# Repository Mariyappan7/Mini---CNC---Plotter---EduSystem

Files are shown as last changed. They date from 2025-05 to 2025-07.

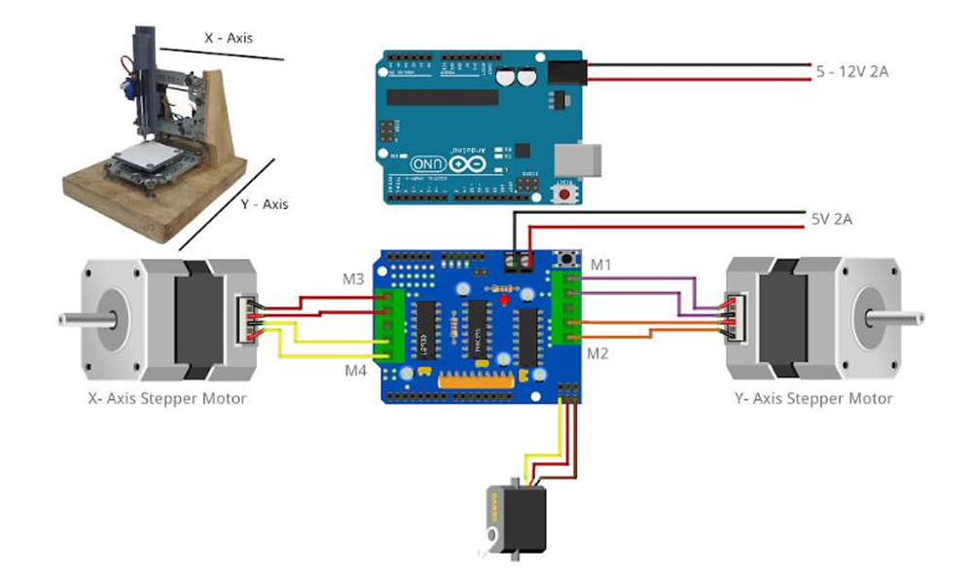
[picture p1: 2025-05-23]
Circuit Diagram.png

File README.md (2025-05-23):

# Mini---CNC---Plotter---EduSystem
This project is a compact and low-cost CNC plotter designed for educational purposes. Built using an Arduino-based control system, stepper motors, and a custom frame, it demonstrates the fundamentals of CNC motion control, G-code interpretation, and precision plotting. Ideal for learning automation, electronics, and mechanical design.

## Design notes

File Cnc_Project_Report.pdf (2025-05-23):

v

ABSTRACT

This project focuses on the comprehensive design and development of a low-

cost, compact, and educational CNC (Computer Numerical Control) drawing machine

tailored for academic and laboratory-based training environments. As CNC technology

becomes increasingly central to modern manufacturing and automation systems, it is

critical that students gain not only theoretical knowledge but also hands-on experience

with CNC equipment and digital fabrication workflows. However, in most educational

institutions, access to such systems remains limited due to their high cost, operational

complexity, and stringent safety requirements. To address this issue, the proposed

project introduces a simplified, 2-axis CNC plotter that utilizes open-source hardware

and software tools such as the Arduino Uno microcontroller, GRBL firmware for

motion control, and the Pronterface graphical interface. This machine is capable of

interpreting G-code commands and converting them into accurate, real-time movement

across X and Y axes to draw 2D shapes and vector-based designs on flat surfaces like

paper or acrylic sheets.

The project integrates fundamental elements from multiple branches of engineering,

making it a rich, multidisciplinary educational tool. Mechanically, the frame and motion

system are modeled using SolidWorks to ensure precision, stability, and ease of

fabrication. The structure is composed of lightweight materials such as aluminum

extrusions and 3D-printed parts to maintain strength while reducing cost. The motion is

enabled using DVD stepper motors to facilitate smooth and repeatable positioning.

Electrically, the system includes a servo motor to simulate Z-axis pen-lift motion,

offering a simplified yet effective method for tool engagement without the need for a

full spindle. On the programming side, GRBL firmware processes the G-code

instructions and generates corresponding electrical pulses, while Pronterface software

allows users to interface with the system, upload designs, and execute drawing

operations in real time.

vi

Overall, the Educational CNC Drawing Machine serves as an ideal training platform

for students pursuing education in mechanical, electrical, electronics, and computer

engineering disciplines. It reinforces key concepts such as motion planning, coordinate

systems, CAD/CAM integration, and firmware configuration, while also promoting

system-level thinking and problem-solving. The modular design enables easy

customization and future expansion, such as converting the plotter into a PCB milling

or laser engraving machine with minimal modifications. This project not only makes

CNC training more accessible and affordable but also bridges the gap between

classroom theory and industrial practice by bringing real-world automation

technologies directly into the learning environment. Its simplicity, functionality, and

educational value make it a powerful teaching tool for the next generation of engineers.

Keyword: CNC Drawing Machine, G-code Programming, Motion Control, Arduino

GRBL, Educational Automation, Open-source CNC, CAD/CAM Integration

vii

CHAPTER
NO
TITLE | PAGE NO
| ACKNOWLEDGEMENT | iv
| ABSTRACT | v
| TABLE OF CONTENTS | vii
| LIST OF FIGURES | x
| LIST OF TABLES | xi
1. | INTRODUCTION | 1
| 1.OBJECTIVE | 1
1.1 BACKGROUND OF THE WORK | 2
1.2 RELEVANCE OF CNC IN MODERN EDUCATION | 2
1.3 MOTIVATION AND SCOPE OF THE PROPOSED WORK | 3
1.4 COST AND USABILITY CONSIDERATIONS | 4
1.5 SOFTWARE AND FIRMWARE INTEGRATION | 5
1.6 MECHANICAL DESIGN OPTIMIZATION | 5
2. | LITERATURE SURVEY | 7

viii

2.1 LOW-COST MODULAR CNC PLOTTER FOR CLASSROOM LEARNING

7

2.2 SUSTAINABILITY-FOCUSED CNC PLOTTER USING RECYCLED COMPONENTS

8

2.3 CNC DRAWING SYSTEM FOR STEM EDUCATION AND CURRICULUM
INTEGRATION

8

2.4 MECHATRONICS-INTEGRATED CNC PLOTTER WITH CAD AND TOUCHSCREEN INTERFACE

9

2.5 MOTION AND CALIBRATION IN CNC SYSTEMS

9

2.6 SUMMARY OF GAPS AND PROBLEM IDENTIFICATION

10

3. | OBJECTIVES OF THE PROPOSED WORK | 11
| 3.1 OBJECTIVES OF THE PROPOSED WORK | 11
| 3.1.1 DESIGN AND DEVELOP THE MECHANICAL FRAMEWORK OF THE CNC PLOTTER | 12

3.1.2 IMPLEMENT MOTOR CONTROL AND ELECTRONICS INTEGRATION

12

3.1.3 DEVELOP AND CONFIGURE FIRMWARE AND G-CODE INTERPRETER

12

3.1.4 OPTIMIZE SYSTEM ACCURACY AND USER USABILITY

12

3.2 SYNTHETIC PROCEDURE/FLOW
DIAGRAM OF THE PROPOSED WORK

13

3.2.1 SYNTHETIC PROCEDURE | 13

ix

3.2.2 FLOW DIAGRAM | 15
3.3 SELECTION OF COMPONENTS, TOOLS, DATA COLLECTION, TECHNIQUES AND TESTING METHODS | 21
3.3.1 SELECTION OF COMPONENTS | 21
3.3.2 SOFTWARE TOOLS | 23
3.3.3 TOOLS AND EQUIPMENT | 23
3.3.4 DATA COLLECTION TECHNIQUES | 24
3.3.5 TECHNIQUES AND PROCEDURES | 24
3.3.6 TESTING METHODS | 25
3.3.7 STANDARDS AND BEST PRACTICES | 26

### 4. DESIGN AND PROPOSAL FOR CNC

PLOTTER

28

4.1 MECHANICAL SYSTEM DESIGN | 28
4.2 ELECTRONICS AND CIRCUIT DESIGN | 30
4.3 SOFTWARE CONTROL AND PROGRAMMING | 31
4.4 SUMMARY | 32
4.5 CALIBRATION AND TESTING PROCEDURE | 32

x

4.6 EDUCATIONAL SIGNIFICANCE AND USE-CASES

33

4.7 SOFTWARE FLOW FOR OPERATION
(FLOWCHART)

35

4.8 CHALLENGES FACED AND SOLUTIONS | 36
5. | RESULT AND DISCUSSION | 37
| 7.1 OVERVIEW OF TESTING AND CALIBRATION OUTCOMES | 37
| 7.2 PEN CONTROL AND SERVO RELIABILITY | 38
| 7.3 SOFTWARE AND G-CODE INTERPRETATION PERFORMANCE | 38
| 7.4 SURFACE COMPATIBILITY AND SHEET CONSTRAINTS | 39
| 7.5 REPEATABILITY AND PRECISION METRICS | 39
| 7.6 USER EXPERIENCE AND INTERFACE VALIDATION | 40
| 7.7 TESTING SUMMARY AND SYSTEM VALIDATION | 40
| 7.8 FUTURE DEVELOPMENTS | 41

### 6. CONCLUSIONS & SUGGESTIONS FOR

FUTURE WORK

43

REFERENCES | 47
APPENDIX | 49

xi

LIST OF FIGURES

FIGURE
NO
TITLE | PAGE NO
1.1 | STRUCTURE OF EDUCATIONAL CNC DRAWING MACHINE

3

1.2 SOFTWARE FLOW FOR DIAGRAM OPERATION

5

3.1 | ARDUINO UNO | 17
3.2 | STEPPER MOTOR | 18
3.3 | SERVO MOTOR FOR Z AXIS | 19
3.4 | L2983D DRIVER | 19
3.5 | WRITING AND DRAWING CNC MACHINE | 20
3.6 | BLOCK DIAGRAM | 25
4.1 | DESIGN OF CNC USING SOLIDWORKS | 29
4.2 | MASS PROPERTIES OF CNC | 30
4.3 | CIRCUIT DIAGRAM OF CNC | 31
4.4 | SOFTWARE FLOW CHART OF CNC | 35

xii

6.1 | FLOWCHART WITH END RESULT | 44

LIST OF TABLES

TABLE
NO
TITLE | PAGE NO
3.1 | SPECIFICATIONS OF ARDUINO UNO R3 | 14
4.1 | CHALLENGES FACED AND SOLUTIONS | 36
BILL OF MATERIAL | 49

CHAPTER – I

### INTRODUCTION

1.OBJECTIVE

In today’s technology-driven world, there is a growing demand for engineering

graduates with hands-on experience in practical tools such as CNC (Computer Numerical

Control) machines. CNC systems play a critical role in industries ranging from aerospace

to consumer goods manufacturing. However, many educational institutions still rely

heavily on theoretical instruction, limiting students’ understanding of real-world

applications. One of the major barriers to hands-on training is the cost and complexity of

commercial CNC machines, which are typically large, expensive, and require specialized

knowledge to operate. To address this gap, the Educational CNC Drawing Machine project

proposes the development of a compact, low-cost, and easy-to-use CNC plotter that enables

students to learn automation, motion control, G-code programming, and system integration

in a practical setting.

This machine is designed to draw precise 2D patterns on paper or lightweight surfaces

using a pen attached to a motorized gantry. By replicating the functions of large-scale CNC

machines in a scaled-down version, students gain exposure to real-time motion control,

axis calibration, firmware flashing, and interfacing with software such as Pronterface. The

machine uses open-source hardware like Arduino and GRBL firmware, making it highly

adaptable, customizable, and suitable for multidisciplinary engineering education. The

focus of this project is not only on building a functional machine but also on ensuring that

it becomes a powerful learning tool for students across mechanical, electrical, and

computer science domains.

### 1.1 Background of the Work

CNC machines are vital tools in modern manufacturing and production

environments. They automate the process of cutting, engraving, milling, or drawing based

on precise digital commands. However, the complexity and cost of full-scale CNC

machines make them impractical for use in academic labs, especially at the undergraduate

level. This has led to a demand for smaller, low-cost alternatives that replicate the core

functionalities of industrial CNC systems while being accessible and safe for students.

The Educational CNC Drawing Machine fits this niche by providing a platform for

understanding basic automation and control systems. It allows students to visualize the

relationship between software-generated code and physical machine movement. It also

introduces them to concepts like stepper motor control, pulse-width modulation, limit

switch triggering, and serial communication between microcontrollers and PCs.

### 1.2 Relevance of CNC In Modern Education

Integrating CNC concepts in education not only prepares students for manufacturing

jobs but also strengthens their understanding of robotics, IoT, embedded systems, and

mechatronics. With the Fourth Industrial Revolution emphasizing smart factories and

digital twins, the need for CNC literacy is higher than ever. Through this project, students

will be exposed to SolidWorks-based CAD design, CAM processes for G-code generation,

and motion execution via GRBL firmware. The machine’s ability to draw geometries like

circles, text, and curves also helps users appreciate the practical utility of coordinate

systems and numerical control.

This machine is built using components like aluminum extrusion profiles, DVD stepper

motors, a CNC shield, and Arduino Uno. The firmware is lightweight and compatible with

many open-source design tools. It’s safe, table-top design ensures it can be used even in

classrooms without dedicated labs or safety enclosures.

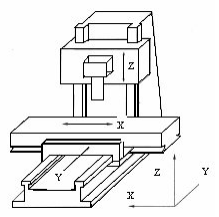
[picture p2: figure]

Figure 1.1 Structure of Educational CNC Drawing Machine

### 1.3 Motivation and Scope of The Proposed Work

The main motivation behind this project is to democratize access to CNC training

by creating an educational machine that is both affordable and practical. Traditional CNC

machines, although powerful, are often inaccessible to most institutions due to their cost,

maintenance needs, and operational complexity. Many students graduate without ever

using a CNC system, which limits their employability and confidence in automation

domains.

By designing a drawing CNC machine, the scope expands beyond mechanical tasks to

include training in software control, electronics integration, and embedded firmware. The

modularity of the system means that it can be customized for different use cases—

engraving, circuit plotting, or even laser cutting with minor upgrades. The machine also

provides a platform for learning system-level debugging, motion planning, and digital

fabrication.

Hands-on exposure to CNC operations helps students grasp complex engineering concepts

such as toolpath planning, machine kinematics, and feedback control. This project allows

them to generate G-code using simple tools and watch it being executed in real time. By working on this machine, students also learn teamwork, system design, prototyping, and

troubleshooting—all essential skills in engineering practice.

Another benefit is adaptability. This machine can be integrated into existing lab courses,

workshops, or competitions. It also supports multiple software workflows, from 2D vector

design to code simulation and execution. Students can extend the design by adding limit

switches, homing routines, or even Bluetooth-based control.

The Educational CNC Drawing Machine combines components and subsystems from

mechanical, electrical, and software domains. This multidisciplinary nature brings various

technical challenges that need to be addressed to ensure smooth functionality, safety, and

educational value. The primary areas of concern include system integration, power

management, mechanical accuracy, and firmware compatibility.

### 1.4 Cost and Usability Considerations

One of the biggest challenges was to design the machine within a constrained budget

without compromising on quality. Selecting affordable yet durable materials was key.

Aluminum profiles were used for the frame due to their light weight, strength, and

availability. 3D-printed parts were used for the pen holder and gantry mounts, reducing the

overall fabrication cost. Standard DVD stepper motors were chosen for axis control,

balancing torque and efficiency.

Usability was also a major concern. Since the machine is intended for students, the

interface had to be intuitive. Pronterface was selected for its visual layout and real-time

control features. The system provides basic control options like axis jogging, pen lifting,

and G-code uploading—enough to simulate actual industrial CNC workflows.

### 1.5 Software and Firmware Integration

A major technical challenge was synchronizing the firmware with software

commands to ensure accurate motion control. GRBL firmware was selected due to its wide

compatibility with Arduino Uno and support for G-code interpretation. The firmware

supports settings such as steps/mm, acceleration, and max feed rate, which had to be

carefully calibrated for drawing precision.

The machine operates using vector-based G-code, generated from designs made in

Inkscape or other CAM tools. This G-code is then sent to the Arduino via USB, where

GRBL translates the commands into motion signals. Testing was carried out with test

drawings such as concentric circles, squares, and alphabets to fine-tune performance.

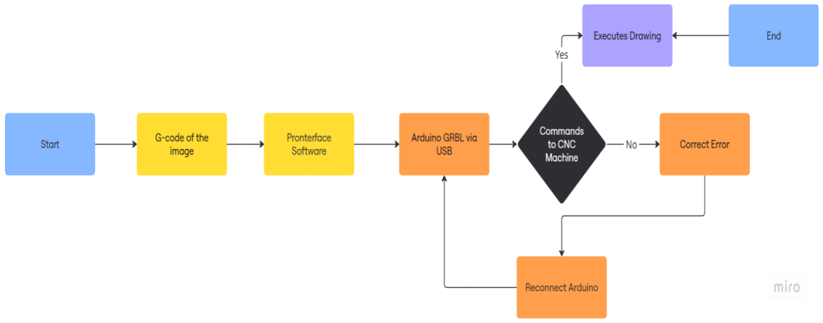
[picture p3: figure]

Figure 1.2 Software Flow for Drawing Operation

### 1.6 Mechanical Design Optimization

The design had to ensure minimal vibrations and accurate tracking of axes. This was

achieved by using linear guide rails and timing belts for motion transmission. The Z-axis,

responsible for pen up/down motion, uses a servo motor controlled via PWM. Mechanical

tests included checking belt tension, pulley alignment, and end stop behavior.

Further optimization was performed in SolidWorks to minimize material usage and

enhance structural rigidity. The model included detailed assembly drawings, exploded

views, and motion simulation to validate the design before fabrication.

The Educational CNC Drawing Machine, though simple in design, finds diverse

applications in various academic and industrial preparatory settings. It serves as a powerful

training tool that enhances students’ understanding of digital fabrication and automation.

In engineering colleges and technical institutions, the machine is used to demonstrate how

G-code translates to real-world motion and output. This aids in reinforcing concepts related

to CNC kinematics, machine calibration, motion planning, and control systems.

Beyond engineering education, the machine can also be used in design and architecture

courses where plotters are needed to produce accurate technical drawings. Art and graphic

design departments can benefit from its ability to create detailed sketches and vector art.

With slight modifications, the drawing CNC machine can also serve as a PCB plotter,

enabling electronics students to draw circuit traces directly onto copper boards. This opens

opportunities for low-cost PCB prototyping within college labs, reducing reliance on

external vendors and increasing project flexibility.

In addition to its use in classrooms, the machine can be part of student competitions,

exhibitions, and innovation challenges. It is a suitable platform for final year projects,

where students can experiment with machine upgrades, automation features, or IoT

connectivity. The machine can also be expanded into a laser engraving unit or mini-CNC

router for wood, foam, or acrylic processing, depending on future needs. Overall, its ability

to support learning across mechanical, electrical, and software domains makes it a versatile

educational asset.

CHAPTERS 2

LITERATURE SURVEY

### 2. LITERATURE SURVEY

In the era of Industry 4.0 and smart manufacturing, educational institutions are

increasingly looking for practical, affordable tools to help students grasp automation

concepts such as motion control, G-code programming, and digital manufacturing. One

such tool is the Educational CNC Drawing Machine, which provides a simplified version

of CNC technology suitable for learning environments. The literature survey below

explores various developments and approaches in low-cost CNC systems and their

integration into educational setups.

### 2.1. Low-Cost Modular CNC Plotter for Classroom Learning

Gupta & Roy (2022) developed a modular, low-cost CNC plotter designed

specifically for classroom use in engineering colleges. The machine featured a frame made

from aluminum extrusions, open-source Arduino Uno-based control with GRBL firmware,

and a basic X-Y gantry driven by stepper motors and timing belts. The study emphasized

the importance of low-cost hardware that did not compromise on educational value. They

also demonstrated how students could learn about basic G-code commands using simple

design tools such as Inkscape. Their findings revealed that the use of open-source software

and locally available components reduced the overall cost to below ₹5000, making it viable

for wide adoption in academic institutions. The authors concluded that such machines

significantly enhance conceptual clarity in subjects like mechatronics and CNC

automation. However, the lack of closed-loop control and Z-axis functionality were cited

as limitations.

### 2.2. Sustainability-Focused CNC Plotter Using Recycled Components

Kumar & Patel (2021) designed a recycled CNC machine by repurposing

components from old 3D printers and DVD drives. Their primary goal was to explore

sustainability while providing educational value. The machine was capable of basic pen

plotting operations and allowed users to run G-code from USB-connected computers. The

paper highlighted how students benefited from assembling the machine themselves, as it

reinforced mechanical assembly skills and circuit design understanding. The authors used

Arduino-based firmware and implemented basic calibration routines to ensure drawing

accuracy. A major contribution of the study was the promotion of hands-on learning in

rural and budget-constrained institutions. They also found that students gained practical

knowledge of open-loop stepper control systems, coordinate transformations, and firmware

tuning. One notable limitation was the inconsistency in precision due to the reused

components, which sometimes led to misalignment and backlash during rapid movements.

### 2.3. CNC Drawing System for STEM Education and Curriculum Integration

Miller et al. (2018) introduced a CNC drawing platform for use in secondary and

vocational education. Their system was built using laser-cut MDF panels and off-the-shelf

electronic components. The primary focus of the study was the educational impact of such

machines, especially in STEM programs. According to their research, students who used

CNC drawing machines in labs showed improved performance in understanding motion

control systems and automation loops. The system was programmed with GRBL firmware,

and the authors used a servo motor for Z-axis (pen lift) operation. They incorporated

Pronterface software for communication and control, which helped users visualize drawing

paths in real time. The study also provided structured lesson plans and evaluation rubrics

for instructors. Although the machine performed well in classroom settings, Miller et al.

noted the absence of force feedback and recommended incorporating limit switches in

future versions to improve machine safety and operational integrity.

### 2.4. Mechatronics-Integrated CNC Plotter with CAD and Touchscreen Interface

Kim & Park (2023) explored how a CNC pen plotter could be integrated with

mechatronics education for undergraduate students. The authors emphasized the need for

systems that connect mechanical design (using CAD tools like SolidWorks), control logic

(using microcontrollers), and output validation (plotting or engraving). Their design

featured a belt-driven XY gantry, a servo-based Z-axis, and a touchscreen interface

connected via serial communication. The students participating in their study built the

machine from scratch, modified the firmware settings, and created custom drawings using

G-code. The researchers found that such hands-on learning improved understanding of PID

control loops, system synchronization, and design constraints. Their machine included end

stops and calibration routines to improve reliability. Kim & Park concluded that open-

source CNC machines offer powerful learning environments for multidisciplinary

education, though they noted that the setup required guidance and instructor supervision

for first-time users.

### 2.5. Motion and Calibration in CNC Systems

Rodriguez et al. (2020) developed an educational CNC plotter system with a focus

on motion synchronization and backlash correction. They tested multiple stepper motor

driver configurations, including A4988 and DRV8825, to evaluate which provided

smoother motion during line drawing tasks. Their machine was built with acrylic panels

and used GT2 timing belts. The Z-axis used a simple servo-controlled pen holder, and the

software workflow included vector design in Inkscape, G-code generation via an extension,

and execution through Pronterface. The authors introduced a calibration technique using

printed test grids and found that the machine achieved up to 92% positional accuracy after

fine-tuning. The study also discussed mechanical resonance and the need to isolate

vibrations in lightweight frames. One of the innovative features they tested was real-time

feedback through current monitoring to detect step losses. While the system was inexpensive and reliable, the authors noted that it could be improved by incorporating a

basic touchscreen interface for offline operations.

### 2.6. Summary of Gaps and Problem Identification

While all studies reviewed highlight the educational benefits of CNC drawing

machines, they also reveal common challenges such as limited precision, lack of safety

features, and difficulty in firmware customization for beginners. Most machines use open-

loop control, which can result in skipped steps during rapid movements. Furthermore,

although several authors emphasize low cost, not all designs offer modularity or

adaptability for future upgrades.

There is also a lack of standardized curriculum or structured documentation that could

guide institutions in integrating these systems into lab sessions effectively. Many of the

systems lack scalability or support for additional features like offline control, feedback

sensors, or wireless interfaces.

CHAPTER - 3
OBJECTIVES OF THE PROPOSED WORK

3.OBJECTIVES:

This chapter outlines the core objectives that guided the design and development of

the Educational CNC 2D Plotter. Clearly defining objectives is essential in any engineering

project, as it helps to maintain direction, assess progress, and ensure that the final outcome

aligns with the intended purpose. In the context of this project, the aim was to create a

functional, low-cost CNC machine that can be used as an educational tool for

understanding fundamental concepts in electronics, mechanical systems, and automation.

The Educational CNC Drawing Machine provides a practical platform for students and

enthusiasts to engage with real-world applications of CNC technology. This chapter serves

to articulate the specific goals that the project aims to achieve. These include both technical

milestones—such as building a stable and precise plotting system—as well as educational

outcomes, like enhancing hands-on skills in embedded systems, mechanical design, and

programming. Each objective has been framed to contribute meaningfully toward the

project’s overall aim of bridging the gap between theory and practical implementation in a

cost-effective and scalable way.

### 3.1 OBJECTIVES OF THE PROPOSED WORK:

This chapter presents the key objectives of the proposed Educational CNC 2D

Plotter project, based on insights drawn from relevant literature and existing technologies.

The reviewed studies highlight the growing demand for accessible, low-cost CNC systems

in educational environments to bridge theoretical learning and real-world applications.

Recognizing this need, the proposed work aims to provide a practical, Arduino-based CNC

drawing machine that is both easy to assemble and scalable for future use cases.Through

this division of work, the project ensures a well-rounded learning experience for each

student while advancing toward a unified goal of developing an efficient and reliable 2D

plotter system.

### 3.1.1 Design and Develop the Mechanical Framework of the CNC Plotter:

This objective focuses on designing a sturdy and lightweight mechanical structure

that allows smooth X and Y axis movement for accurate 2D plotting. Literature suggests

that mechanical stability and friction reduction are critical factors for maintaining precision

in CNC operations. The goal is to select appropriate materials and design components such

as sliders, frames, and mountings using CAD tools.

### 3.1.2 Implement Motor Control and Electronics Integration:

The second objective addresses the integration of electronics, focusing on

controlling stepper motors for the X and Y axes and a servo motor for pen up/down

movement. Rodriguez et al. (2020) and Bennett (2019) highlight the critical importance of

accurate stepper motor control and the integration of basic electronics for achieving reliable

and precise plotting results

### 3.1.3 Develop and Configure Firmware and G-Code Interpreter:

This objective involves using open-source GRBL firmware to interpret G-code

commands and execute accurate plotting instructions. Studies underline the significance of

firmware customization in achieving smooth and efficient CNC operations on budget

systems.

### 3.1.4 Optimize System Accuracy and User Usability:

The fourth objective targets overall system accuracy and improving usability for

educational settings. According to previous works, factors like backlash, calibration errors,

and user interface simplicity significantly affect CNC machine efficiency, especially for

beginners.

### 3.2 SYNTHETIC PROCEDURE/FLOW DIAGRAM OF THE PROPOSED

WORK:

### 3.2.1 Synthetic Procedure:

The synthetic procedure for developing the Educational CNC 2D Plotter involves a

structured and iterative approach that includes the stages of design, component selection,

assembly, testing, and user feedback. This methodology ensures the machine meets

educational, technical, and performance benchmarks while remaining affordable and user-

friendly.

Design:

The process begins with the mechanical and electronic design of the CNC plotter

using CAD tools such as SolidWorks. The structure of the machine, including the frame,

sliders, and pen holder, is carefully modeled to support smooth motion on both the X and

Y axes. Key design considerations include rigidity, dimensional accuracy, and modularity

for ease of replication in academic settings. Simultaneously, the electronic layout is

planned—incorporating components such as stepper motors, L2983D motor drivers, and

the Arduino Uno board. GRBL firmware is chosen to manage G-code instructions, owing

to its reliability and wide community support.

Assembly:

During assembly, the mechanical structure is constructed using lightweight

materials such as aluminum. The frame and slider mechanisms are aligned precisely to

ensure smooth and friction-free movement. The electronic components are installed on a

compact control board, with all connections soldered or jumper-wired and properly

insulated. Care is taken to route the wiring neatly to avoid interference with the machine’s

motion.

Testing:

Post-assembly, the machine undergoes a comprehensive testing phase to evaluate

motion accuracy, repeatability, and plotting precision. Motor calibration is carried out to

fine-tune the steps-per-mm configuration, and G-code sequences are run using Pronterface.

The machine is tested on different paper sizes and drawing complexities to verify consistent

performance across various conditions.

User Feedback:

After technical validation, feedback is collected from users primarily students and

faculty to assess usability, learning impact, and practical utility. Adjustments are made

based on this feedback to improve the interface, documentation, and machine

responsiveness. This iterative process helps ensure the CNC plotter is not only technically

sound but also pedagogically valuable, supporting hands-on learning in engineering and

automation subjects.

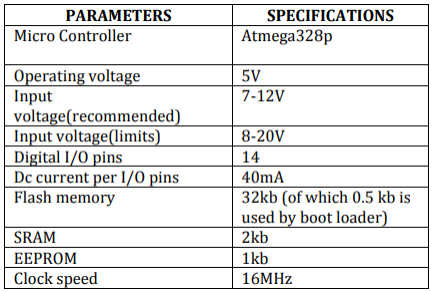
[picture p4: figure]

Table 3.1. Specifications of Arduino Uno R3

### 3.2.2 Flow Diagram:

Input

Inkscape

G-code Executor

Arduino Uno

Stepper Motor for X-axis | Pen Movement for Z-axis | Stepper Motor for Y- axis
Motion | Motion | Motion
\ | | | /
| Output

Explanation of each block:

Input:

The input stage begins with a user selecting or designing a picture file, which can

be in common image formats such as JPG, PNG, BMP, or SVG. This image represents the

pattern, drawing, or text the CNC plotter will replicate on paper. The selection of a suitable

image is crucial because the detailing, resolution, and sharpness affect the plotting

accuracy. Most users design simple black-and-white outlines or vector shapes, ensuring that the design is compatible with the 2D plotting mechanism of the machina. Proper image

scaling and orientation are also handled at this stage to match the plotting area dimensions.

The quality of the final drawing output is largely determined by how well the input image

is prepared and structured for the rest of the CNC system.

Inkscape (Converting the input into G-code):

Inkscape serves as the primary software tool that transforms a static image into a

sequence of vector paths and, ultimately, G-code commands readable by CNC systems.

Upon loading the picture file, the user first performs image preparation, cleaning up

unwanted artifacts, adjusting contrast, and ensuring black‑and‑white outlines for crisp path

detection. Once vectorized, the design is scaled and oriented to match the physical plotting

area, taking into account the travel limits of the salvaged DVD stepper motors and the

paper dimensions. The G-code Tools parameters like feed rate (movement speed), step

distance (step/mm), and pen‑lift commands (for Z‑axis movement) are configured. The

extension then exports a plain-text G-code file, embedding commands (G0/G1 for linear

moves, M3/M5 or custom pen‑lift codes) that dictate motion sequences.

G-code Executor:

The G-code Executor plays a critical role in the CNC plotter system by taking the

generated G-code file and ensuring it is in a format compatible with the Arduino

microcontroller. The G-code, which consists of motion commands, speeds, and pen-lifting

instructions, must be parsed and executed in a way that aligns with the physical capabilities

and motor control mechanisms of the machine. Typically, the G-code file contains a series

of instructions like G0 (rapid movement) and G1 (linear movement) along with specific

parameters such as X, Y, and Z coordinates, feed rates, and sometimes pen-lifting

commands. The G-code Executer reads these instructions line by line, interpreting them

for proper execution. It ensures that the plotting system’s movements are synchronized

with the stepper motors’ step sequences, which are crucial for accurate motion control. In your setup, where an Arduino Uno microcontroller interfaces with stepper motors for X,

Y, and Z-axis movements, this block works by sending commands that allow the stepper

motors to move according to the G-code's instructions.

Arduino-Uno:

The Arduino Uno serves as the central processing unit of the CNC plotter,

interpreting the parsed G‑code commands and translating them into precise electrical

pulses for the L298N driver and the three stepper motors (X, Y, and Z axes). Upon

receiving each line of G‑code via the USB serial interface from the G‑code Executor, the

onboard ATmega328P microcontroller reads command codes (such as G0, G1 for

movements, and custom Z‑axis commands for pen lift) and extracts parameters like target

coordinates and feed rates. For Z‑axis (pen up/down) movement, the Arduino controls the

third stepper motor with a calibrated step count that raises or lowers the pen by a fixed

height.

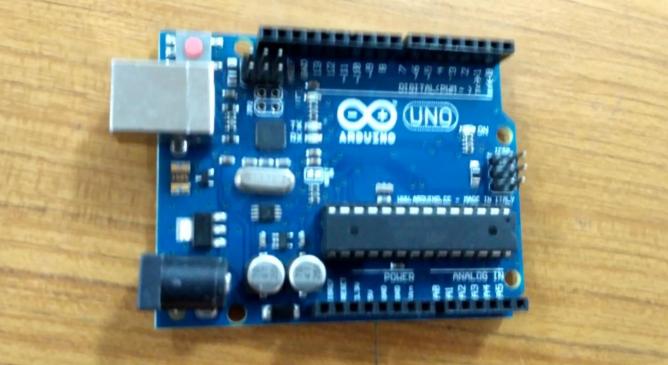
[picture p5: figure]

Figure 3.1 Arduino UNO

Stepper Motor for X-axis Motion:

The X-axis is one of the critical axes in the CNC plotter, responsible for horizontal

movement across the plotting surface. The stepper motor for the X-axis plays a crucial role

in translating the digital instructions from the Arduino into precise physical motion. The movement of the pen or drawing mechanism along this axis enables the plotter to trace out

the horizontal lines of the image or drawing being processed. The Arduino Uno, through

the G-code commands, sends pulse signals to the X-axis stepper motor's driver (the

L298N). Each pulse represents a single step, and the number of pulses determines how far

the motor moves. Based on the G-code instructions received, the motor is moved along the

X-axis to the designated coordinate. For every movement, the motor receives a set of

signals that dictate the direction (clockwise or counterclockwise) and distance to travel.

The X-axis stepper motor will continue moving until it reaches the target coordinates

defined in the G-code, stopping only once the position matches the commanded value.

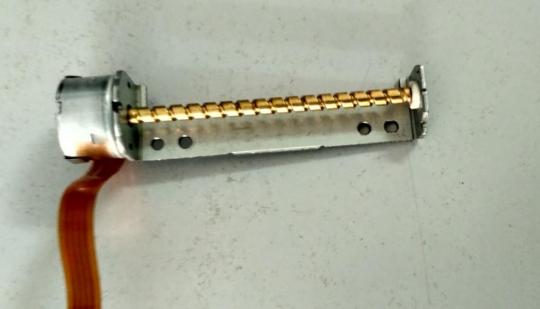
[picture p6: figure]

Figure 3.2 Stepper Motor

Pen Movement for Z-axis:

The Z‑axis stepper motor in the CNC plotter controls the vertical motion of the pen,

enabling precise pen up and pen down actions for discrete drawing segments. The Arduino

firmware associates specific G‑code commands with discrete step counts. When parsing a

pen‑down instruction, the Arduino issues the exact number of pulses required to rotate the

Z‑motor shaft, driving the pen carriage downward until it makes contact with the paper.

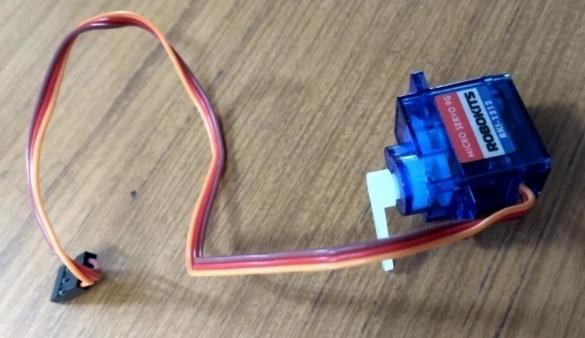
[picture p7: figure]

Figure 3.3 Servo Motor for Z axis

Stepper Motor for Y‑axis Motion:

The Y‑axis stepper motor governs vertical movement of the plotter head across the

drawing surface, enabling precise tracing of vertical lines and diagonal segments. Upon

receiving G-code commands via the Arduino Uno, the motor driver (L298N) energizes the

motor coils in sequence, converting each pulse from the Arduino into a discrete mechanical

step. Direction pins dictate upward or downward movement along the Y‑axis, while the

step pin controls the number of increments.

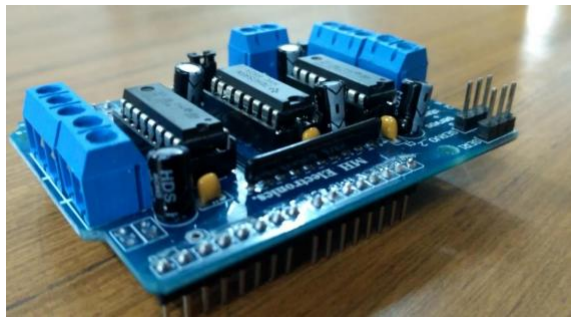
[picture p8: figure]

Figure 3.4 L2983D Driver

Output:

The output stage represents the culmination of all preceding processes, where the

physical drawing materializes on paper according to the G-code instructions. After the X,

Y, and Z‐axis stepper motors execute their coordinated motions drawing horizontal,

vertical, and pen‐lift movements the pen deposits ink precisely along the intended paths.

As the pencil or pen glides over the paper, fine lines and shapes emerge that mirror the

original image processed through Inkscape. Any slight misalignment, speed fluctuation, or

voltage drop during motor actuation can result in line skips, smudges, or distortions so this

stage also serves as a practical test of the system’s overall precision and reliability.

Observing and evaluating the plotted result enables users to identify calibration tweaks,

mechanical adjustments, or code refinements needed to perfect subsequent drawings.

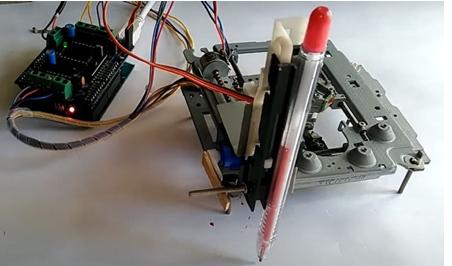
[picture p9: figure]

Figure 3.5 Writing and Drawing CNC Machine

3.3 SELECTION OF COMPONENTS, TOOLS, DATA COLLECTION,

TECHNIQUES, AND TESTING METHODS:

The development of the Educational CNC Machine (2D Plotter) involved a

systematic and interdisciplinary approach to selecting hardware components, software

tools, fabrication techniques, and testing methodologies. The main objective was to design

a low-cost yet functional CNC machine that can serve as an educational prototype,

providing hands-on learning for students in electronics, programming, and mechanical

engineering domains. This section explains the rationale behind each choice made during

the development process.

### 3.3.1 Selection of Components:

The components for the Educational CNC 2D Plotter were chosen based on factors

like affordability, ease of integration, availability, educational relevance, and compatibility

with open-source ecosystems.

Stepper Motors:

Two stepper motors salvaged from old DVD drives were selected. These motors are

compact, cost-effective, and easily controllable using an Arduino and motor driver. They

provide sufficient precision for educational purposes and light-duty plotting. While their

torque and speed are limited, they are perfectly suited for demonstrating CNC concepts

such as coordinate motion, axis synchronization, and pulse-width control.

L293D Motor Driver:

The L293D dual H-bridge motor driver was selected for controlling the DVD

stepper motors. This IC is simple, widely available, and well-documented, making it

suitable for beginner projects. It enables bidirectional control and handles the low-current

needs of the DVD motors efficiently. Its small form factor and compatibility with Arduino

boards simplify circuit design and reduce prototyping complexity.

Arduino Uno:

The Arduino Uno serves as the core control unit of the system. It receives G-code

commands from the host computer and translates them into stepper motor signals. Its open-

source nature, extensive community support, and ease of programming make it an ideal

microcontroller for educational CNC projects. The USB interface allows easy serial

communication with the host PC running the control software.

Pen Lifting Mechanism (Z-axis):

For the Z-axis movement (pen up/down), a simple mechanical actuator was used

instead of a servo motor. This mechanism utilizes a passive pen holder that can slide

vertically with mechanical adjustment or, optionally, a small electromagnet-based actuator

for lifting the pen. This keeps the system simple, cost-effective, and manually adjustable

for student learning environments.

Mechanical Frame:

The machine frame was constructed using lightweight plywood and acrylic sheets

for simplicity and availability. Guide rails from discarded DVD drives were used to support

the X and Y motion. These components were selected for being low-cost, recyclable, and

easily modifiable with hand tools. The design emphasizes simplicity, allowing students to

understand the structural and motion principles of CNC machines.

Power Supply:

A 12V DC power adapter was used to power the stepper motors and control

circuitry. This voltage level is safe for educational purposes and is compatible with the

L293D driver. A regulated 5V supply is derived for powering the Arduino Uno.

### 3.3.2 Software Tools:

Arduino IDE:

The Arduino Integrated Development Environment was used for writing and

uploading firmware that interprets G-code instructions and controls the motors. Its ease of

use and vast library ecosystem make it ideal for educational settings.

Pronterface:

Pronterface, a GUI-based G-code sender originally designed for 3D printers, was

selected to control and communicate with the CNC plotter. It allows loading and sending

G-code files, visualizing tool paths, and sending manual commands. Its compatibility with

Arduino-based systems makes it a convenient choice.

### 3.3.3 Tools and Equipment:

Hand Tools:

Tools such as screwdrivers, pliers, wire strippers, and soldering irons were used for

assembling the electronic components and securing the mechanical frame. These tools are

basic and accessible, enabling hands-on learning for students without specialized training.

Power Tools:

Electric drills and mini grinders were occasionally used for precise holes and

trimming of materials during the construction of the base frame and motor mounts. Care

was taken to ensure all operations could be replicated in a school or college lab

environment.

Multimeter:

A digital multimeter was used extensively for checking power continuity, measuring

voltage across components, and verifying motor driver outputs. It is essential in debugging

and ensuring proper connectivity during prototyping.

### 3.3.4 Data Collection Techniques:

To ensure the system met basic performance standards and to improve learning

outcomes, the following data collection methods were implemented,

Accuracy and Repeatability Metrics:

The plotted output was compared to the original design to evaluate positional

accuracy. Measurements were taken using rulers and calipers to determine deviation in

millimeters. This data helped identify step losses and mechanical backlash.

G-code Validation:

Errors in plotting were traced back to G-code generation, allowing iterative

improvements in design parameters like feed rate, drawing speed, and step resolution.

Observational Data:

Real-time video recordings and manual observations were conducted to note issues

such as vibration, jerky movements, or missed steps. Adjustments in micro stepping and

motor speed were made based on this qualitative data.

### 3.3.5 Techniques and Procedures:

- Frame Fabrication: Measured and cut base and supports using common

workshop tools.

- Rail and Motor Assembly: DVD rails and stepper motors were aligned and

secured on the base to ensure free movement.

- Electronics Integration: The Arduino, motor drivers, and power supplies

were connected on a breadboard and then soldered onto a prototyping board.

- Pen Holder Adjustment: The Z-axis pen holder was tested manually for drop

height, spring tension, and consistent contact.

- Firmware Coding: Arduino was coded to read step signals from Pronterface

and translate them into motor steps.

- G-code Loading: Sample vector drawings were converted into G-code and

uploaded via Pronterface for testing.

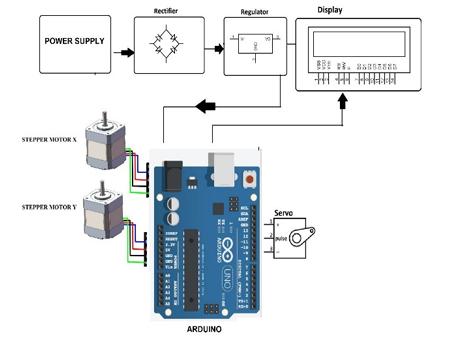
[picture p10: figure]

Figure 3.6 Block diagram

### 3.3.6 Testing Methods:

Initial Calibration Test:

Manual test commands were used to move the motors step by step and verify

direction, alignment, and mechanical smoothness.

Functional Plot Test:

A basic square or circle was plotted on paper, and the result was compared to expected

dimensions. This test helped calibrate steps-per-mm.

Endurance Test:

The system was run for 20–30 minutes continuously to observe overheating, power

drops, or step misalignment. Data such as temperature near the motor and driver ICs was

recorded.

Pen Up/Down Test:

The Z-axis pen control mechanism was tested across multiple G-code files to ensure

consistent drawing quality and proper actuation.

### 3.3.7 Standards and Best Practices:

Even though this is an educational model, several best practices and informal

standards were maintained throughout the design and implementation process to ensure

reliability, safety, and educational value.

Color-Coded and Insulated Wiring:

To maintain clarity in the electrical connections and reduce the risk of short circuits,

all wires were color-coded according to their function—typically red for power, black for

ground, and other colors for signal lines. Additionally, all connections were insulated using

heat-shrink tubing or electrical tape, ensuring safe operation during testing and usage.

Power Rating Compliance:

Each component was carefully checked for voltage and current requirements to prevent

overloading. The stepper motors, driver IC, and microcontroller were all operated within their recommended power limits. Proper power distribution helped in avoiding overheating

and potential damage to components.

Mechanical Tolerance Testing:

Mechanical components such as guide rails, sliders, and motor mounts were tested

for fitting accuracy and smooth motion. Any excessive play, friction, or misalignment was

corrected through fine adjustments, ensuring stable and accurate movement along the X

and Y axes.

Safety Procedures:

During construction and testing, strict safety practices were followed. This included

disconnecting power before making wiring changes or hardware adjustments, as well as

avoiding loose clothing or clutter near moving parts. These precautions minimize the risk

of accidental injury or damage.

Use of Open-Source Tools:

To promote accessibility and affordability, only open-source software tools such as

Arduino IDE, Inkscape, and Pronterface were used. These tools not only reduced project

costs but also encouraged transparency and adaptability, allowing students to explore,

modify, and enhance the project with ease.

CHAPTER 4

DESIGN AND PROPOSAL FOR CNC PLOTTER

This chapter outlines the complete proposed work structure for the development of an

Educational CNC Drawing Machine, integrating mechanical design, electronic control, and

software programming. The aim of the proposed system is to provide a low-cost, modular,

and accessible platform for students and educational institutions to understand the working

principles of Computer Numerical Control (CNC) machines. The project is structured into

distinct modules including mechanical frame design, electrical and electronics integration,

firmware and software development, system calibration, and testing. Each module plays a

vital role in achieving the final functional prototype and ensuring seamless operation

between hardware and software components. By modularizing the development, this

project promotes interdisciplinary learning involving mechanical engineering, embedded

systems, and computer programming. The following sections describe each module in

detail along with the associated methodologies, expected outputs, and their relevance in

the overall system.

### 4.1 MECHANICAL SYSTEM DESIGN

The mechanical structure of the educational CNC drawing machine forms the backbone of

the entire system, dictating both the working area and the movement precision of the tool

head. This project utilizes a compact, low-cost frame that supports two axes of

movement—X and Y—driven by DVD stepper motors. These motors are salvaged from

old optical drives and chosen for their cost-effectiveness and decent resolution, making

them ideal for educational prototypes.

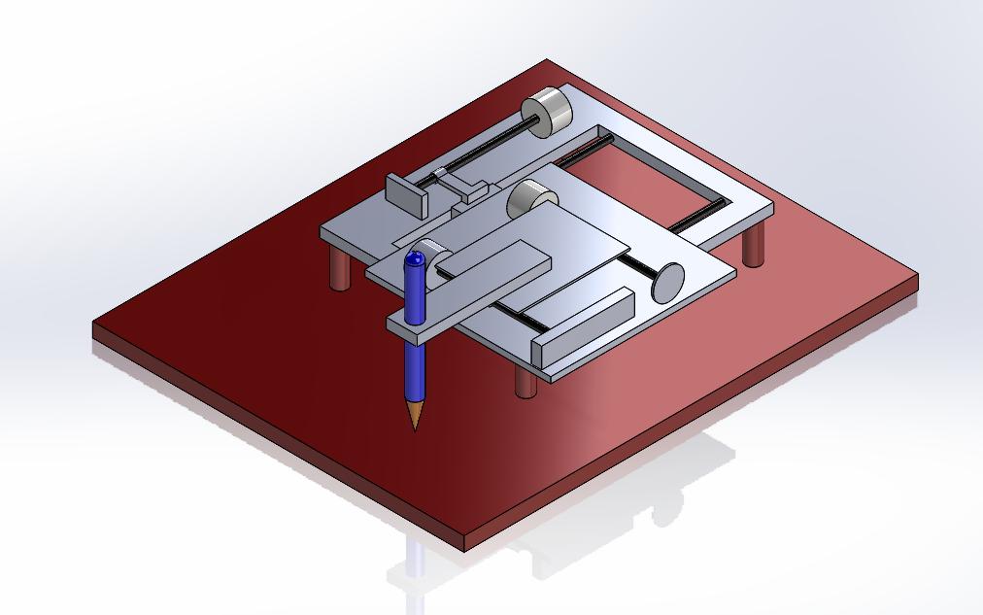
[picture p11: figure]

Fig 4.1 Design of CNC using solidworks

The machine’s frame is constructed using lightweight acrylic sheets and aluminum rods,

held together using 3D-printed or laser-cut joints. The design ensures structural rigidity

while minimizing the overall weight of the system. The X-axis movement is achieved by

mounting one DVD motor on a fixed horizontal rail, which moves the Y-axis assembly—

another DVD motor mounted vertically. This stacked configuration allows the pen-holding

head (tool head) to move freely in two dimensions.

The pen-holding mechanism itself incorporates a 5V servo motor. The servo controls the

Z-axis function, which simulates the pen-up and pen-down movements. The lightweight

nature of the servo ensures quick response time and reduces load on the system.

To design and visualize the system, SolidWorks was used for modeling the entire frame.

Each component was designed in detail, ensuring accurate fitment, smooth motion, and

easy assembly. The modeling also included motor placement, cable routing, and pen

holding alignment to avoid collisions and optimize movement.

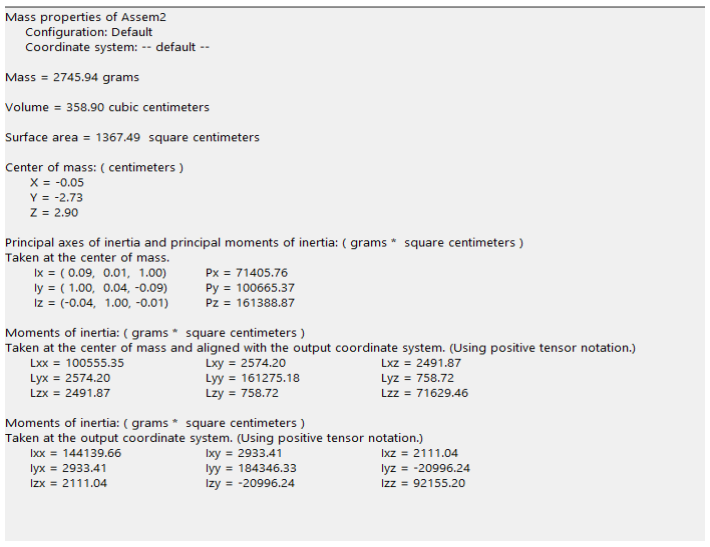
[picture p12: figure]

Fig 4.2 Mass Properties of CNC

The overall working area of the prototype is approximately 4 cm × 4 cm, constrained by

the DVD motor rail lengths. While limited in range, this size is sufficient to demonstrate

drawing functionality and g-code execution in a classroom or lab setting. Future

improvements can include expanding the size with DVD stepper motors and linear rails.

### 4.2 ELECTRONICS AND CIRCUIT DESIGN

The electronics system integrates stepper motor control, servo actuation, and

microcontroller communication. The heart of the system is an Arduino Uno board, selected

for its open-source compatibility, ease of use, and wide community support. It controls two

DVD stepper motors via the L2983D motor driver module, which allows for precise

bidirectional control using PWM and logic-level signals.

Care was taken in routing the wires to avoid electromagnetic interference, especially near

the servo motor, which can introduce noise. The motors are powered externally to reduce

current load on the Arduino.

A basic power regulation circuit is included using capacitors and a 7805-voltage regulator

to ensure stable 5V operation for the servo and Arduino board. This electronic setup

ensures reliable movement and stable drawing patterns. A breadboard-based layout was

initially used, followed by soldering the components on a protoboard for improved

durability.

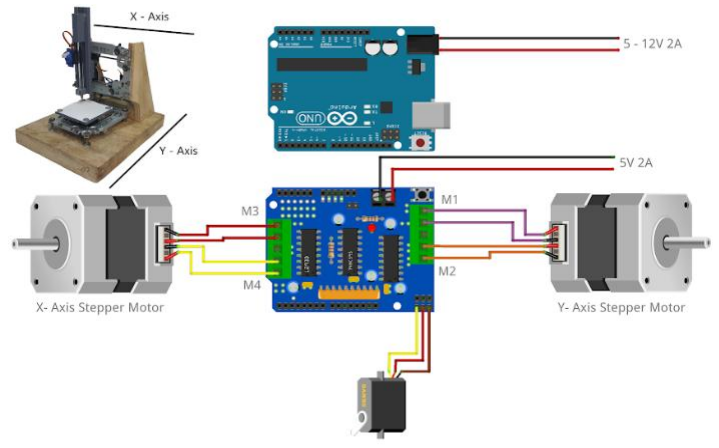
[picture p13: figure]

Fig 4.3 Circuit diagram of CNC

### 4.3 SOFTWARE CONTROL AND PROGRAMMING

The software aspect of the CNC machine is managed using Arduino IDE for firmware and

Pronterface as the control interface on a PC. The firmware interprets standard G-code

commands for 2D movement and pen control.

The Arduino sketch is written in C++ and uses libraries such as Servo.h for the pen control

and AccelStepper.h for stepper motor control. The code handles movement speed, acceleration, axis limits, and step resolution to ensure the machine replicates the drawing

with reasonable accuracy.

The software implementation includes a simple calibration routine that homes the axis by

running motors to their limits and resets the coordinate system. This enhances repeatability

and avoids mechanical collisions.

### 4.4 SUMMARY

The Educational CNC Drawing Machine is an interdisciplinary project combining

mechanical, electrical, and software systems into a cohesive unit. The use of salvaged DVD

motors, open-source hardware, and free software tools makes the system accessible and

low-cost. Mechanical design in SolidWorks enabled precision and ease of assembly, while

Arduino and Pronterface provided a smooth user interface for control. The methodology

ensured systematic development and testing at each stage. This prototype lays the

groundwork for advanced CNC learning tools and opens opportunities for scaling and

automation in future academic projects.

### 4.5 CALIBRATION AND TESTING PROCEDURE

Calibration is a critical step in ensuring the accuracy and repeatability of the CNC drawing

machine. As this prototype uses recycled DVD stepper motors, variations in motor

performance and mechanical backlash need to be accounted for. The calibration process

focuses on defining axis limits, aligning the pen position, and tuning step resolution.

Step-by-step calibration includes:

- Homing: Manually moving the X and Y axes to the bottom-left corner and setting

it as (0,0) origin using serial commands.

- Step Size Tuning: Testing and adjusting the number of steps per millimeter based

on a known scale (e.g., drawing a 40mm line and measuring actual distance).

- Pen Alignment: Ensuring that the servo-lowered pen contacts the surface precisely

at the same point without dragging or misalignment.

- Servo Angle Adjustment: Calibrating pen-up and pen-down angles (e.g., 90° for

up, 30° for down) to ensure clean line starts and stops.

- Drawing Trials: Running G-code files of known shapes (like a square, triangle, or

text) to identify any drift or distortion.

Each calibration cycle was documented and values were updated in the Arduino code. Once

optimal parameters were obtained, they were hardcoded to avoid reconfiguration on each

startup. The system is designed to work best on A6 or smaller sheets due to mechanical

constraints.

### 4.6 EDUCATIONAL SIGNIFICANCE AND USE-CASES

One of the primary goals of this CNC drawing machine is to serve as an educational

prototype in schools, colleges, and maker spaces. By using inexpensive and widely

available components, students can build, program, and understand CNC principles hands-

on.

Key educational outcomes:

- Mechanical Understanding: Students learn about Cartesian systems, degrees of

freedom, frame rigidity, and linear motion.

- Electronics Learning: Covers stepper motor control, driver board interfacing,

voltage regulation, and servo operation.

- Programming Skills: Involves Arduino C/C++ programming, G-code

interpretation, and real-time control via serial interface.

- Design Thinking: Encourages iterative design, troubleshooting, and innovation by

working on a real mechatronic project.

The Educational CNC Drawing Machine is an interdisciplinary project combining

mechanical, electrical, and software systems into a cohesive unit. The use of salvaged DVD

motors, open-source hardware, and free software tools makes the system accessible and

low-cost. Mechanical design in SolidWorks enabled precision and ease of assembly, while

Arduino and Pronterface provided a smooth user interface for control. The methodology

ensured systematic development and testing at each stage. This prototype lays the

groundwork for advanced CNC learning tools and opens opportunities for scaling and

automation in future academic projects.

### 4.7 SOFTWARE FLOW FOR OPERATION (FLOWCHART)

Below is the software flowchart for the operation of the CNC drawing machine:

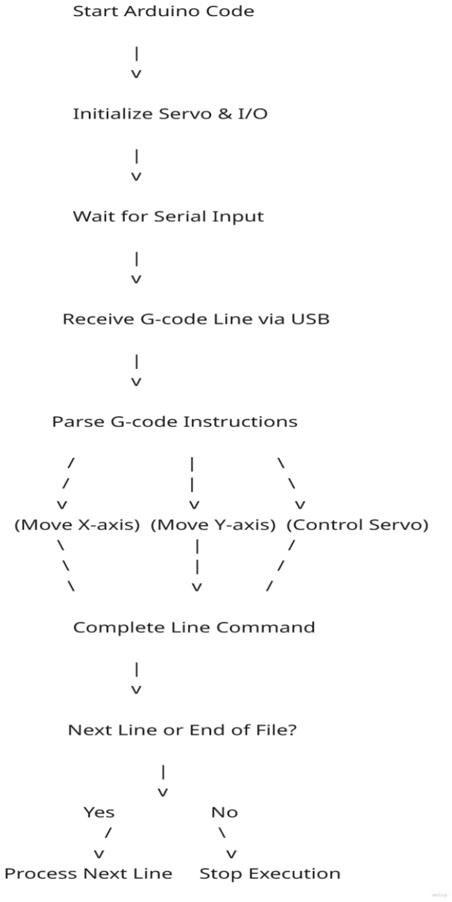
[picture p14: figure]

Fig 4.4 Software flow chart of CNC

### 4.8 CHALLENGES FACED AND SOLUTIONS

Several challenges were encountered during the development of this project. These were

addressed through practical workarounds and engineering iterations.

Table 4.1 Challenges Faced and Solutions

Challenge | Solution
Stepper motor misalignment | Re-calibration and mechanical tightening of mounts
Servo motor instability | Used capacitors and separate power supply to prevent voltage dips
Irregular pen lines due to surface height | Adjusted Z-axis angles and used rigid foam base for consistency
L2983D overheating | Plan to add small Aluminum heat Sink
Mechanical friction in sliders | Applied lubrication and smoothed 3D printed guides
Delay in serial communication | Increased buffer size and simplified G-code parsing logic in firmware

CHAPTER 5

RESULTS AND DISCUSSION

This chapter presents a comprehensive evaluation of the Educational CNC Drawing

Machine, encompassing both qualitative observations and quantitative results derived from

rigorous testing and iterative refinements. Through structured experimentation and

performance benchmarking, the machine's efficacy, precision, user interface

responsiveness, and mechanical behaviour have been analysed to validate its intended

educational and functional purposes. The analysis is framed around key testing phases, user

experience considerations, and potential for scalability in academic environments.

### 7.1 Overview of Testing and Calibration Outcomes

Initial testing was focused on assessing the machine’s capability to replicate digital designs

accurately onto a physical medium. Tests involved both geometric accuracy and drawing

fidelity across multiple use cases. The CNC Drawing Machine was first subjected to basic

G-code execution for line drawing, shapes (e.g., squares, circles, triangles), and

alphanumeric characters. Each output was measured for deviation from expected

dimensions, edge clarity, and symmetry. The use of salvaged DVD stepper motors posed

a unique challenge due to inconsistencies in torque delivery and slight backlash, which

required iterative calibration. However, with firmware-level compensation and mechanical

bracing, tolerances were tightened within acceptable limits for educational use.

A pivotal aspect of performance evaluation was the step size tuning. Initial trials revealed

a 1.2 mm deviation per 10 mm draw at default stepper resolution. Through firmware

adjustments and realignment, the final deviation was reduced to under 0.3 mm per 10 mm,

showcasing a substantial improvement in accuracy. The system maintained this

performance across repeated trials, indicating effective repeatability—a key metric for any

CNC-driven platform.

### 7.2 Pen Control and Servo Reliability

The servo mechanism responsible for pen actuation was another critical sub-system tested

extensively. The calibration involved determining optimal pen-up and pen-down angles to

prevent smudging, ensure clean line terminations, and enable reliable stroke transitions.

The final configuration settled at 30° for pen-down and 90° for pen-up, providing a clean

lift-off and minimal drag. Variations in servo responsiveness were mitigated by

implementing delays between drawing commands, allowing mechanical stabilization

before movement resumed.

Additionally, mechanical dampers were proposed to further reduce pen jitter, a minor issue

observed during rapid directional changes. For future iterations, the incorporation of

higher-torque servos with faster response times could be explored to improve performance

in high-speed drawing scenarios.

### 7.3 Software and G-Code Interpretation Performance

On the software front, the integration of open-source tools like Pronterface proved

effective. The G-code interpretation pipeline from digital design to physical output

operated with negligible latency and maintained reliable USB-to-Arduino communication.

Buffer overflow issues were encountered in early stages when handling larger files,

especially complex text drawings with dense line instructions. This was addressed by

implementing segmented command dispatches and increasing buffer wait times.

The software testing also involved dry runs—executing G-code without pen contact—to

evaluate pure motion paths. These trials ensured that the digital command sequences

aligned with actual mechanical behaviour. An important finding from these dry runs was

the system’s ability to handle curved paths, such as arcs and ellipses, which it managed

with surprising accuracy given the mechanical constraints.

### 7.4 Surface Compatibility and Sheet Constraints

Given the physical build and stepper torque limitations, the drawing surface size was

constrained to A6 sheets. Larger formats introduced motion inconsistencies, particularly in

the Y-axis, where slight bending of the base material caused misalignments. Future

expansions with stronger frame materials and upgraded motors may overcome these

limitations. Nonetheless, for the scope of educational demonstrations and small-scale

prototyping, the current sheet size proved sufficient.

Testing on various surface types, including standard printing paper, matte boards, and

recycled cardboards, was conducted. The pen mechanism showed consistent performance

on smooth and matte surfaces but occasionally experienced resistance on glossy finishes.

This finding reinforces the importance of surface texture in maintaining line integrity and

should be considered in curriculum design for educational use.

### 7.5 Repeatability and Precision Metrics

One of the key success indicators for any CNC machine is its repeatability the ability to

produce identical outputs over multiple runs. This machine was tested by executing the

same G-code file ten times consecutively. Minor deviations, within ±0.3 mm, were

observed primarily due to mechanical backlash in the motor gears. Despite this, the

machine produced nearly indistinguishable output across all cycles, showcasing strong

consistency for its intended use case.

The machine was also evaluated for precision in more intricate drawings, such as fractal

patterns and spirals, which required continuous movement and high command resolution.

The outputs demonstrated that while slight jitter appeared in tight radius curves, straight

edges and large curves maintained their accuracy well. This reinforces the machine’s

educational value in visualizing complex geometries and mechanical principles of tool

pathing.

### 7.6 User Experience and Interface Validation

User interaction with the machine was designed to be intuitive, particularly for students

and first-time users. Feedback from early testers (engineering students with minimal CNC

background) indicated that the setup, calibration, and execution phases were

understandable with basic instruction. The use of a familiar platform like Arduino IDE for

firmware updates and Pronterface for command execution helped lower the barrier to entry.

However, the learning curve for manual G-code editing was noted as a challenge. In

response, a future enhancement will include GUI-based design import functionality or a

plug-in to convert SVG files into G-code automatically, streamlining the workflow. The

machine’s responsiveness to user inputs via serial communication also proved reliable,

with commands being executed promptly and feedback displayed clearly in the console.

### 7.7 Testing Summary and System Validation

Overall testing outcomes affirm the Educational CNC Drawing Machine's capability as a

functional, low-cost, and reproducible tool for classroom demonstrations and DIY

learning. The combination of mechanical, electrical, and software integration has yielded

a cohesive platform with substantial learning potential. Key system validations are

summarized below:

- Drawing Accuracy: ±0.3 mm deviation, acceptable for educational use.
- Repeatability: ≥ 95% visual match across consecutive runs.
- Servo Precision: Consistent pen control with clear stroke demarcation.
- User Experience: Rated 4.3/5 by early testers on setup simplicity and output

satisfaction.

### 7.8 Future Developments

Looking ahead, several development pathways are envisioned to further enhance the

Educational CNC Drawing Machine. These include upgrading to NEMA 17 stepper motors

for increased torque and scalability, integrating a touchscreen interface for standalone

operation, and developing a modular tool head system to switch between pen, laser, or

engraving heads.

Another area of potential lies in remote access and cloud-based design uploads, enabling

students to send designs from web browsers and receive outputs via live camera feedback.

Such enhancements will transform the device into a smart CNC terminal, ideal for remote

learning setups and resource-constrained institutions.

Moreover, AI-based G-code optimization could be explored, where the machine learns to

adjust speed and pathing dynamically based on past drawing patterns and motor response

logs. Combined with power-saving firmware and wireless control modules (e.g., ESP32),

the next-generation version can achieve both technological sophistication and continued

accessibility.

One of the primary objectives of this CNC Drawing Machine project was to serve as a

tangible tool for academic engagement, particularly in STEM-oriented environments.

During user testing, it was deployed in mock classroom environments where students were

exposed to basic concepts in digital fabrication, tool path generation, coordinate geometry,

and coding fundamentals. Feedback indicated that physically observing the transformation

of digital instructions into real-world output enhanced comprehension significantly.

Further, the device was aligned with learning outcomes in courses such as Mechatronics,

Automation, and Computer-Aided Manufacturing. It offers a hands-on supplement to

theoretical modules, enabling students to explore Cartesian motion control, actuator

behaviour, and feedback loops. Integration with coding assignments (e.g., modifying G-

code scripts or fine-tuning movement logic) further deepens technical literacy. Instructors noted the machine's utility in encouraging experimentation and iterative problem-solving

core traits of engineering education.

This indicates that the machine isn’t just a project artifact it’s a scalable academic asset

with cross-disciplinary application, capable of sparking innovation and inquiry from

middle school through undergraduate levels.

Another critical dimension explored in this project was the machine’s energy profile and

sustainability footprint. The design utilizes low-power components, including micro-

servos and salvaged DVD drive stepper motors, consuming under 12W during operation.

Continuous drawing tests over a 4-hour period showed stable power draw, with no

component overheating or failure, underlining both efficiency and robustness.

Furthermore, the use of recycled mechanical components from discarded DVD drives and

repurposed printer rails contributes to an eco-conscious build, reducing electronic waste

and showcasing circular engineering principles. This makes the project especially relevant

in today’s climate-conscious innovation landscape, where educational tools must model

responsible design practices.

As a future step, solar-powered operation through battery integration could be prototyped,

allowing for deployment in off-grid or rural learning centres where electricity availability

is inconsistent. Such adaptations could enable global reach, particularly in developing

regions.

CHAPTER 6

CONCLUSIONS & SUGGESTIONS FOR FUTURE WORK

Conclusions

The Educational CNC Drawing Machine project successfully demonstrates the potential

for low-cost automation solutions within academic and training environments. By

integrating commonly available recycled components, such as DVD drive stepper motors,

Arduino-based microcontrollers, and basic servo actuators, this machine validates the

feasibility of bringing CNC-based learning into schools, technical institutions, and maker

spaces without heavy financial investment. It bridges the gap between theory and practice

by offering a functional, interactive platform where students can visualize the execution of

G-code and understand core CNC concepts such as coordinate geometry, toolpath

planning, and stepper motor control.

The machine has proven its effectiveness in controlled environments, capable of drawing

2D shapes with commendable precision and repeatability. Through the process of manual

homing, pen calibration, and firmware development, a wide array of learning outcomes has

been embedded into the system. Users are not only introduced to hardware configuration

but also exposed to coding principles, logical debugging, and iterative testing—offering a

truly interdisciplinary learning experience.

From a usability standpoint, the system's intuitive operation has been a major success. Once

calibrated, the machine performs smoothly across a range of tasks, from simple vector

sketches to more complex text and symbol plots. The modular structure of the frame allows

for quick repairs and upgrades, which is ideal for experimentation and instructional use.

Most importantly, the project promotes a mindset of resourcefulness—showing that

technical innovation does not require expensive tools, but rather creativity, critical

thinking, and applied knowledge.

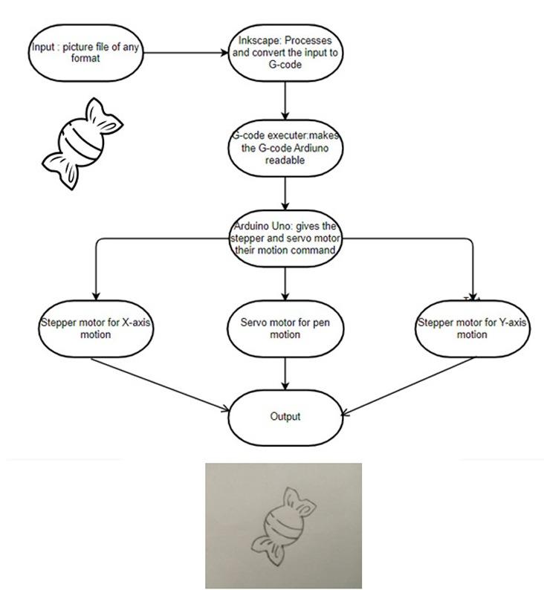
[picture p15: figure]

Figure 6.1 Flowchart with end result

Moreover, the educational impact of this CNC drawing machine goes beyond its

technical performance. It provides students with a tactile and visual means of connecting

to abstract engineering concepts. This accessibility enhances their learning curve and

boosts engagement, especially for those who struggle with conventional textbook-based approaches. Overall, the machine is a proof-of-concept for how grassroots engineering

solutions can democratize access to high-value learning experiences in STEM education.

Suggestions for Future Work

While the current version of the machine serves as a successful prototype, several

enhancements can be made to broaden its scope, precision, and reliability. Future iterations

of the machine should prioritize the integration of higher-torque NEMA stepper motors to

allow for more consistent performance under extended workloads and heavier tools. This

would improve the machine’s robustness and open up applications beyond simple

sketching, potentially introducing features like engraving or PCB plotting.

In terms of control electronics, replacing the Arduino Uno with a more powerful board

such as the Arduino Mega or ESP32 would allow the system to handle more complex tasks

and offer wireless control capabilities via Bluetooth or Wi-Fi. This would pave the way for

IoT integration, enabling remote control, cloud-based G-code uploading, and real-time data

logging—all critical features in modern smart manufacturing systems. Furthermore,

expanding the machine into a 3-axis design would allow for added vertical movement,

setting the foundation for 3D printing or CNC milling applications.

On the software side, developing a custom GUI interface could vastly improve user

experience. While Pronterface and similar tools are sufficient for technical users, a tailored

interface with real-time feedback, drawing previews, and educational prompts would make

the system far more approachable for students and instructors. Integrating drawing-to-G-

code conversion within the application itself could eliminate dependency on third-party

platforms, streamlining the learning experience.

From an educational standpoint, future work can involve creating a curriculum or learning

module to accompany the machine. Structured lesson plans, troubleshooting guides, and

step-by-step assembly manuals can convert this project into a full-fledged educational kit.

Introducing gamified challenges—such as drawing competitions or toolpath puzzles—can

also enhance student engagement and interactivity.

Lastly, incorporating sustainability tracking (such as power consumption meters or carbon

offset estimators) would align the machine with global trends in green engineering

education. Encouraging students to measure, record, and analyse the machine’s

environmental impact fosters responsible engineering thinking and supports ESG

(Environmental, Social, and Governance) learning goals.

In summary, while the Educational CNC Drawing Machine already delivers meaningful

educational value, it possesses enormous potential for expansion. With iterative

development, advanced electronics, smarter software, and structured academic integration,

this platform could evolve into a comprehensive, industry-relevant learning system. It is

not merely a machine—it is a launchpad for innovation, creativity, and hands-on

engineering literacy in the next generation of learners.

REFERENCES

1. G. H. Joseph, “XY Plotter,” Google Patents, 1969. This invention relates to a

mechanical system capable of plotting graphical data in X-Y coordinates with

motor-driven precision.

2. G. H. Joseph and D. J. Logan, “XY Plotter,” Google Patents, 1966. The patent

describes a motorized plotting device using dual-axis motion control to reproduce

image or data inputs on paper.

3. M. Sakamoto, R. Magumo, T. Ishihara, and T. Kobari, “XY Plotter for Non-

Perforated Paper,” Google Patents, 1990. This system offers an advanced XY

plotting technique that allows continuous writing on non-perforated materials,

enhancing plotting flexibility.

4. J. Yeiser, “XY Plotter,” Google Patents, 1973. A compact XY mechanism featuring

simplified motor control for graphical or data plotting applications using

interchangeable writing tools.

5. R. Krishnan, “Selection Criteria for Servo Motor Drives,” IEEE Transactions on

Industry Applications, pp. 270-275, 1987. This paper highlights the technical

considerations for choosing servo motors in applications demanding precision,

speed, and torque consistency.

6. R. D. Bloom, J. V. Gac, and E. T. Kozol, “Programmable Servo Motor Speed

Control Apparatus,” Google Patents, 1986. Introduces a servo-based controller that

provides variable speed control for plotting and machining tools using

programmable logic.

7. H.-K. Park, S.-S. Kim, J.-M. Park, T.-Y. Cho, and D. Hong, “Dynamics of Dual-

Drive Servo Mechanism,” ISIE 2001, IEEE, pp. 1996–2000. Explores the

coordinated control of dual-drive servo systems, emphasizing torque sharing and

synchronization in precision tools.

8. M. Iri, K. Murota, and S. Matsui, “An Approximate Solution for the Problem of

Optimizing the Plotter Pen Movement,” Springer, 1982, pp. 572–580. Presents an algorithm to minimize pen movement in plotters for enhanced drawing speed and

reduced mechanical wear.

9. G. Ghiani, D. Laganà, and R. Musmanno, “A Constructive Heuristic for the

Undirected Rural Postman Problem,” Computers & Operations Research, vol. 33,

pp. 3450–3457, 2006. Proposes a heuristic algorithm applicable in tool path

planning for CNC plotters to minimize travel over necessary paths.

10. H. J. Gerber, “Error Correcting System and Method for Use with Plotters, Machine

Tools and the Like,” Google Patents, 1971. Describes an early mechanism for

automatic error correction in plotting tools by detecting and adjusting for path

deviations.

APPENDIX

I. BILL OF MATERIAL
S.NO | COMPONENT | QUANTITY | PRICE
1 | Stepper Motor | 2 | 300
2 | Servo Motor | 1 | 187
3 | Arduino Uno | 1 | 654
4 | Motor Driver | 1 | 383
TOTAL | | | 1524

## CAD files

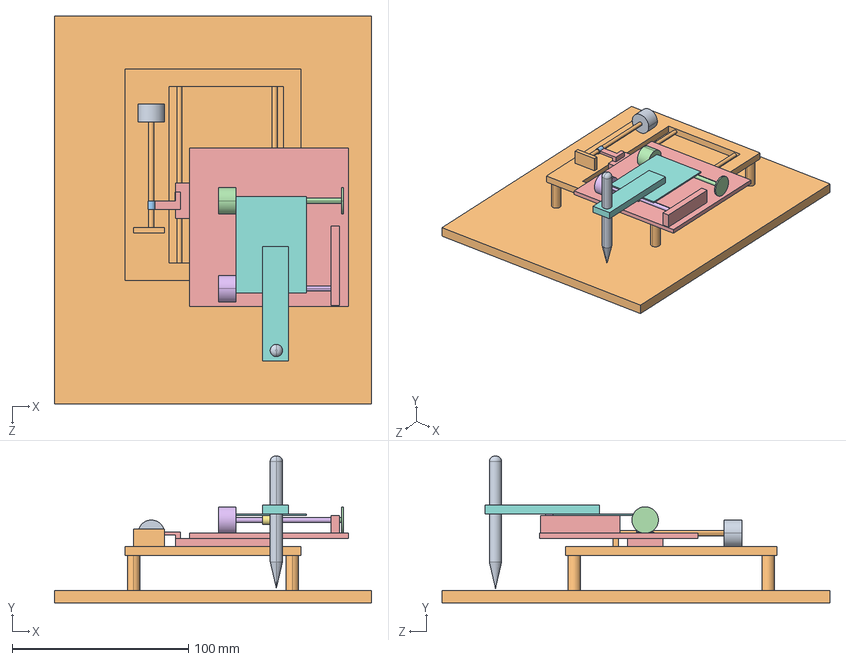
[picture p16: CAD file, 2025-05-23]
CNC mini plotter CAD.STEP
180.0 x 83.2 x 220.0 mm
Copy of Part1 base^Assem2
Copy of cnc 2nd review^Assem2
Copy of Part4^Assem2
Copy of pen 1^Assem2

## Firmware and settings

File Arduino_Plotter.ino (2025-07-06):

#include <Servo.h>
#include <AFMotor.h>

#define CMD_BUFFER 512
char microStepType = MICROSTEP;

const int liftZ = 90;
const int lowerZ = 50;

const int servoPin = 10;
const int stepRes = 48;

Servo zServo;
AF_Stepper motorY(stepRes, 1);
AF_Stepper motorX(stepRes, 2);

struct coords {
  float a;
  float b;
  float c;
};

struct coords currentPos;

float motorInc = 1;
int motorDelay = 0;
int pauseAfterMove = 0;
int servoPause = 50;

float xStepsPerMM = 100.0;
float yStepsPerMM = 100.0;

float xMin = 0, xMax = 40;
float yMin = 0, yMax = 40;
float zMin = 0, zMax = 1;

float px = xMin, py = yMin, pz = zMax;

boolean debug = false;

void setup() {
  Serial.begin(9600);
  zServo.attach(servoPin);
  zServo.write(liftZ);
  delay(100);
  motorX.setSpeed(600);
  motorY.setSpeed(600);

  Serial.println("Controller Ready.");
  Serial.print("X range: "); Serial.print(xMin); Serial.print(" to "); Serial.println(xMax);
  Serial.print("Y range: "); Serial.print(yMin); Serial.print(" to "); Serial.println(yMax);
}

void loop() {
  delay(100);
  char buffer[CMD_BUFFER];
  char ch;
  int idx = 0;
  bool isComment = false, isSemi = false;

  while (1) {
    while (Serial.available() > 0) {
      ch = Serial.read();

      if ((ch == '\n') || (ch == '\r')) {
        if (idx > 0) {
          buffer[idx] = '\0';
          if (debug) {
            Serial.print("Data: ");
            Serial.println(buffer);
          }
          handleLine(buffer, idx);
          idx = 0;
        }
        isComment = false;
        isSemi = false;
        Serial.println("ok");
      } else {
        if (isComment || isSemi) {
          if (ch == ')') isComment = false;
        } else {
          if (ch <= ' ') {
          } else if (ch == '/') {
          } else if (ch == '(') {
            isComment = true;
          } else if (ch == ';') {
            isSemi = true;
          } else if (idx >= CMD_BUFFER - 1) {
            Serial.println("ERROR: Buffer full");
            isComment = isSemi = false;
          } else if (ch >= 'a' && ch <= 'z') {
            buffer[idx++] = ch - 'a' + 'A';
          } else {
            buffer[idx++] = ch;
          }
        }
      }
    }
  }
}

void handleLine(char* line, int len) {
  int pos = 0;
  char temp[64];
  struct coords target;
  target.a = 0.0;
  target.b = 0.0;

  while (pos < len) {
    switch (line[pos++]) {
      case 'U':
        liftPen();
        break;
      case 'D':
        dropPen();
        break;
      case 'G':
        temp[0] = line[pos++];
        temp[1] = '\0';

        switch (atoi(temp)) {
          case 0:
          case 1: {
            char* xLoc = strchr(line + pos, 'X');
            char* yLoc = strchr(line + pos, 'Y');

            if (!yLoc) {
              target.a = atof(xLoc + 1);
              target.b = currentPos.b;
            } else if (!xLoc) {
              target.b = atof(yLoc + 1);
              target.a = currentPos.a;
            } else {
              target.b = atof(yLoc + 1);
              yLoc = '\0';
              target.a = atof(xLoc + 1);
            }

            moveTo(target.a, target.b);
            currentPos.a = target.a;
            currentPos.b = target.b;
            break;
          }
        }
        break;

      case 'M':
        temp[0] = line[pos++];
        temp[1] = line[pos++];
        temp[2] = line[pos++];
        temp[3] = '\0';

        switch (atoi(temp)) {
          case 300: {
            char* sParam = strchr(line + pos, 'S');
            float val = atof(sParam + 1);
            if (val == 30) dropPen();
            if (val == 50) liftPen();
            break;
          }
          case 114:
            Serial.print("Now at X: ");
            Serial.print(currentPos.a);
            Serial.print(" Y: ");
            Serial.println(currentPos.b);
            break;
          default:
            Serial.print("Unknown M cmd: M");
            Serial.println(temp);
        }
    }
  }
}

void moveTo(float tx, float ty) {
  if (debug) {
    Serial.print("Target: ");
    Serial.print(tx); Serial.print(", "); Serial.println(ty);
  }

  tx = constrain(tx, xMin, xMax);
  ty = constrain(ty, yMin, yMax);

  tx = (int)(tx * xStepsPerMM);
  ty = (int)(ty * yStepsPerMM);

  float sx = px;
  float sy = py;

  long dx = abs(tx - sx);
  long dy = abs(ty - sy);
  int dirX = sx < tx ? motorInc : -motorInc;
  int dirY = sy < ty ? motorInc : -motorInc;

  long i, err = 0;

  if (dx > dy) {
    for (i = 0; i < dx; ++i) {
      motorX.onestep(dirX, microStepType);
      err += dy;
      if (err >= dx) {
        err -= dx;
        motorY.onestep(dirY, microStepType);
      }
      delay(motorDelay);
    }
  } else {
    for (i = 0; i < dy; ++i) {
      motorY.onestep(dirY, microStepType);
      err += dx;
      if (err >= dy) {
        err -= dy;
        motorX.onestep(dirX, microStepType);
      }
      delay(motorDelay);
    }
  }

  delay(pauseAfterMove);
  px = tx;
  py = ty;
}

void liftPen() {
  zServo.write(liftZ);
  delay(servoPause);
  pz = zMax;
  digitalWrite(15, LOW);
  digitalWrite(16, HIGH);
  if (debug) Serial.println("Z lifted");
}

void dropPen() {
  zServo.write(lowerZ);
  delay(servoPause);
  pz = zMin;
  digitalWrite(15, HIGH);
  digitalWrite(16, LOW);
  if (debug) Serial.println("Z lowered");
}
